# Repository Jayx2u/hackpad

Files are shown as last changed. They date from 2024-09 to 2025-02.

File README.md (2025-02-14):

# JayPad
My first PCB design. A macropad made for the YSWS Hack Club event [Hackpad](https://github.com/hackclub/hackpad). Got too many modded Minecraft keybinds...
## Showcase
Front Photo
Back Photo
Front Photo Alt 2
## PCB
Font of PCB
Back of PCB
## Case
Case Design
## Renders
Render 1
Render 2
## Acknowledgement
- MX Cherry switches symbol, footprint and model from [sszczep/kicad-libraries/](https://github.com/sszczep/kicad-libraries/tree/master)
- Cute cats from [Neko Atsume](https://www.nekoatsume.com/en/)

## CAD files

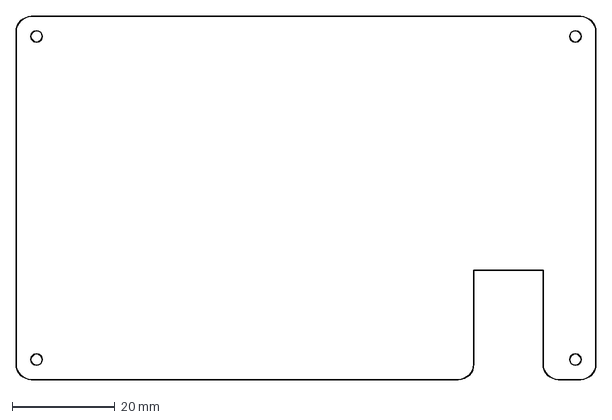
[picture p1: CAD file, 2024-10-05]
case/jaypad-bottomv2-frosted-acrylic-3mm.dxf
113.0 x 70.8 mm

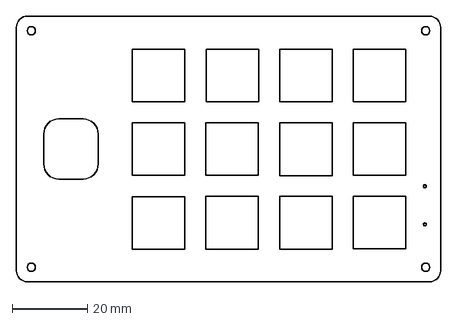
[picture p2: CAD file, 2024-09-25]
case/jaypad-top-acrylic-3mm.dxf
113.0 x 70.8 mm

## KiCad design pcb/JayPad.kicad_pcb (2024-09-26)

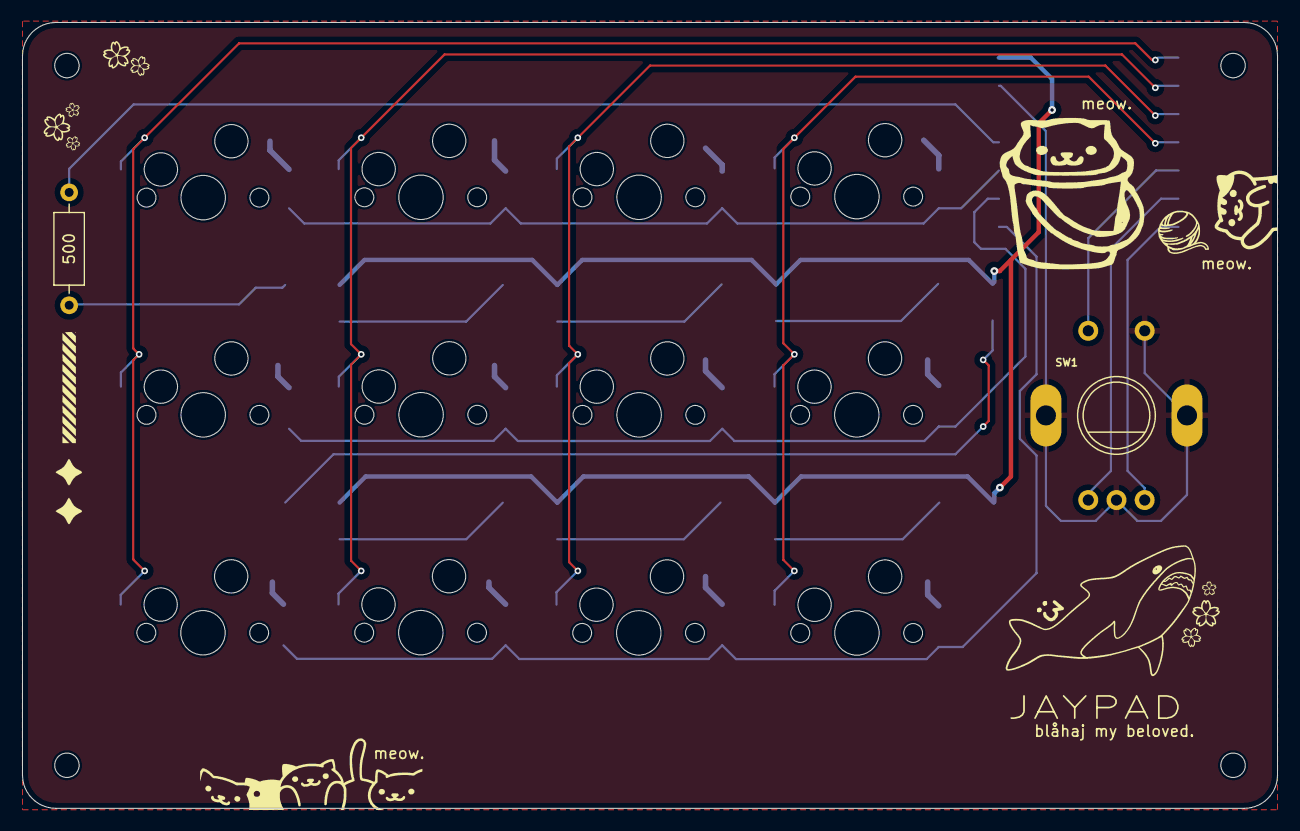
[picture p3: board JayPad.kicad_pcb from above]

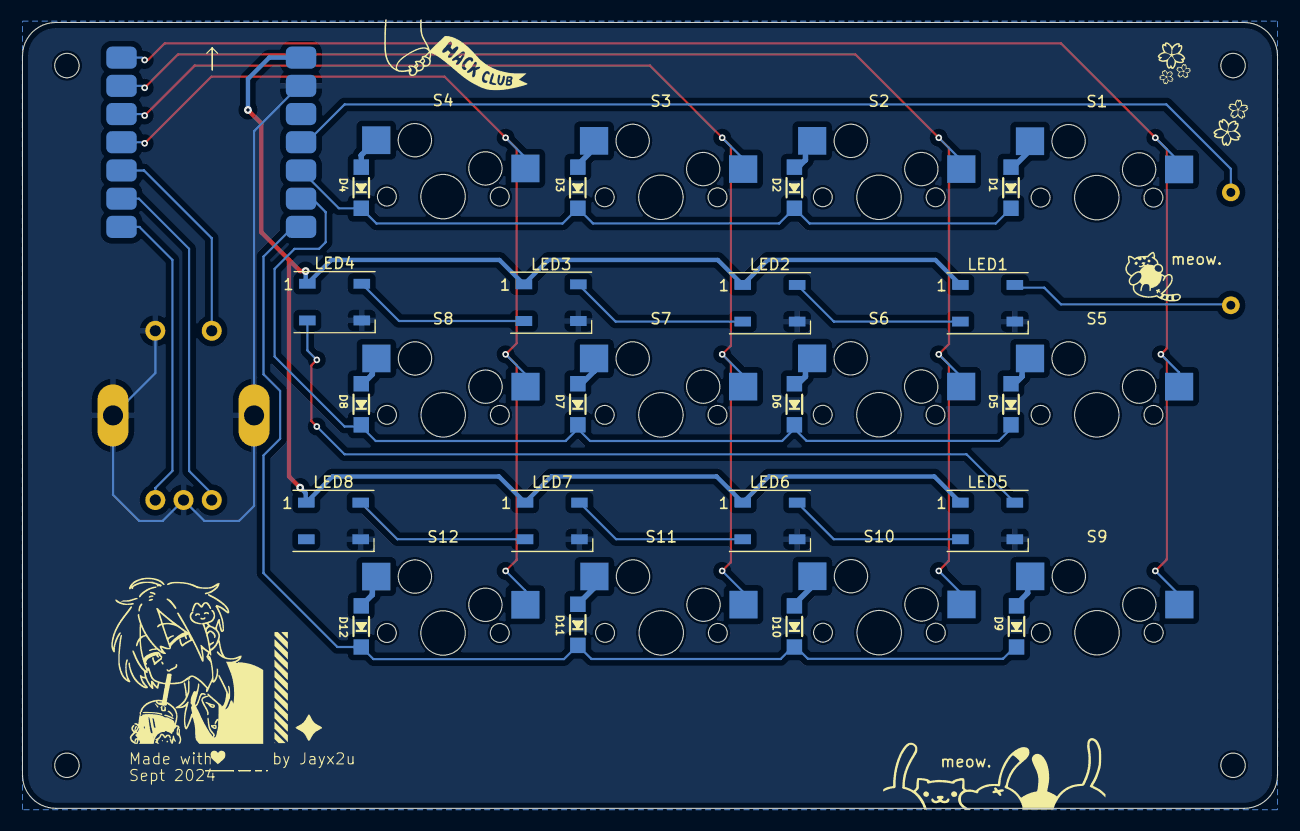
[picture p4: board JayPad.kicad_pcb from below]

Board: 2 copper layers, 113.0 x 70.8 mm, 36 parts (21 on the bottom side), 33 nets.

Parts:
:3: LOGO
D1, D2, D3, D4, D5, D6, D7, D8, D9, D10, D11, D12: 1N4148W; MICROBUILDER_SOD-123
LED1, LED2, LED3, LED4, LED5, LED6, LED7, LED8: WS2812B; LED_WS2812B_PLCC4_5.0x5.0mm_P3.2mm
M1: MOUDLE-SEEEDUINO-XIAO; MOUDLE14P-SMD-2.54-21X17.8MM
R1: 500; R_Axial_DIN0207_L6.3mm_D2.5mm_P10.16mm_Horizontal
S1, S2, S3, S4, S5, S6, S7, S8, S9, S10, S11, S12: CherryMX; CherryMX_1.00u_KailhSocket
SW1: PEC11-4215F-S24; ADAFRUIT_ELECTROMECH_PEC11+SWITCH

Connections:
+5V: LED1.1 (VDD), LED2.1 (VDD), LED3.1 (VDD), LED4.1 (VDD), LED5.1 (VDD), LED6.1 (VDD), LED7.1 (VDD), LED8.1 (VDD), M1.14 (5V)
COL0: M1.1 (PA02_A0_D0), S1.1, S5.1, S9.1
COL1: M1.2 (PA4_A1_D1), S2.1, S6.1, S10.1
COL2: M1.3 (PA10_A2_D2), S3.1, S7.1, S11.1
COL3: M1.4 (PA11_A3_D3), S4.1, S8.1, S12.1
DOUT0: LED4.2 (DOUT), LED5.4 (DIN)
ENC_A: M1.6 (PA9_A5_D5_SCL), SW1.P$A
ENC_B: M1.7 (PB08_A6_D6_TX), SW1.P$B
ENC_SW: M1.5 (PA8_A4_D4_SDA), SW1.P$1
GND: LED1.3 (VSS), LED2.3 (VSS), LED3.3 (VSS), LED4.3 (VSS), LED5.3 (VSS), LED6.3 (VSS), LED7.3 (VSS), LED8.3 (VSS), M1.13 (GND), SW1.P$2, SW1.P$C, SW1.P$GND1, SW1.P$GND2
unnamed: D1.A, S1.2
unnamed: D2.A, S2.2
unnamed: D3.A, S3.2
unnamed: D4.A, S4.2
unnamed: D5.A, S5.2
unnamed: D6.A, S6.2
unnamed: D7.A, S7.2
unnamed: D8.A, S8.2
unnamed: D9.A, S9.2
unnamed: D10.A, S10.2
unnamed: D11.A, S11.2
unnamed: D12.A, S12.2
unnamed: LED3.2 (DOUT), LED4.4 (DIN)
unnamed: LED2.2 (DOUT), LED3.4 (DIN)
unnamed: LED1.2 (DOUT), LED2.4 (DIN)
unnamed: LED1.4 (DIN), R1.2
unnamed: LED5.2 (DOUT), LED6.4 (DIN)
unnamed: LED6.2 (DOUT), LED7.4 (DIN)
unnamed: LED7.2 (DOUT), LED8.4 (DIN)
RGB: M1.11 (PA6_A10_D10_MOSI), R1.1
ROW0: D1.C, D2.C, D3.C, D4.C, M1.10 (PA5_A9_D9_MISO)
ROW1: D5.C, D6.C, D7.C, D8.C, M1.9 (PA7_A8_D8_SCK)
ROW2: D9.C, D10.C, D11.C, D12.C, M1.8 (PB09_A7_D7_RX)

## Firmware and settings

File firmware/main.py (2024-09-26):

print("Waking Up ~w~")

import board

from kmk.kmk_keyboard import KMKKeyboard
from kmk.keys import KC
from kmk.scanners import DiodeOrientation

from kmk.modules.encoder import EncoderHandler
from kmk.extensions.RGB import RGB
from kmk.extensions.RGB import AnimationModes

keyboard = KMKKeyboard()

# Backlight
rgb = RGB(
    pixel_pin=board.D10,
    num_pixels=8,
    animation_mode=AnimationModes.RAINBOW,
)
keyboard.extensions.append(rgb)

# Xiao RP2040 RGB LED
rgbOnBoard= RGB(
    pixel_pin=board.NEOPIXEL,
    num_pixels=1,
    animation_mode=AnimationModes.RAINBOW,
)
keyboard.extensions.append(rgbOnBoard)

# Switch Matrix Pins
keyboard.col_pins = (board.D0, board.D1, board.D2, board.D3)
keyboard.row_pins = (board.D9, board.D8, board.D7)
keyboard.diode_orientation = DiodeOrientation.COL2ROW

# 4x3 Matrix Keymap
keyboard.keymap = [
    [KC.RGB_TOG],
    [KC.MUTE],
    [KC.P1],
    [KC.P2],
    [KC.P3],
    [KC.P4],
    [KC.P5],
    [KC.P6],
    [KC.P7],
    [KC.P8],
    [KC.P9],
    [KC.P0],
]

# Rotary Encoder
encoder_handler = EncoderHandler()
encoder_handler.divisor = 2
encoder_handler.pins = (board.D5, board.D6, board.D4)
encoder_handler.map = (KC.VOLD, KC.VOLU, KC.MUTE)
keyboard.modules.append(encoder_handler)

if __name__ == '__main__':
    keyboard.go()

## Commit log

2024-09-22 Fixed incorrect switch references
    [JayPad.kicad_pcb]
2024-09-23 Copper zone set to GND, optimised COL & GND traces
    [JayPad.kicad_pcb]
2024-09-23 Fixed GND traces not following DRC
    [JayPad.kicad_pcb]
2024-09-23 Changed some trace routes & moved some silkscreen
    [JayPad.kicad_pcb]
2024-09-23 Fixed LED cutout shape
    [JayPad.kicad_pcb]
2024-09-23 LEDs now using GND copper pour & routed ROW0 which I somehow forgot to do
    [JayPad.kicad_pcb]
2024-09-24 Changed from RGB backlight to underglow
    [JayPad.kicad_pcb, JayPad.kicad_sch]
2024-09-24 Added some lil silkscreen decor
    [JayPad.kicad_pcb]
2024-09-25 Added a bit more decor and changed resistor placement
    [JayPad.kicad_pcb]
2024-09-25 Added case files
    [jaypad-bottom-frosted-acrylic-3mm.dxf, jaypad-top-acrylic-3mm.dxf]
2024-09-25 Removed rulers
    [JayPad.kicad_pcb]
2024-09-25 Corrected switch plate hole positions
    [jaypad-top-acrylic-3mm.dxf]
2024-09-26 Added RGB and rotary encoder functions
2024-09-26 Added one lil cat decor
    [JayPad.kicad_pcb]
2024-09-26 Added gerbers
    [JayPad-B_Cu.gbr, JayPad-B_Mask.gbr, JayPad-B_Paste.gbr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]
2024-10-05 Added fillets to microcontroller cutout
    [jaypad-bottomv2-frosted-acrylic-3mm.dxf.dxf]
2024-10-21 Fixed file name
    [jaypad-bottomv2-frosted-acrylic-3mm.dxf]
2024-10-21 Added drill files
    [JayPad-NPTH.drl, JayPad-PTH.drl]
